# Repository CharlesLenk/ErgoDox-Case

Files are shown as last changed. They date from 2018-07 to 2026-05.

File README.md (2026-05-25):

# ErgoDox Case

ErgoDox keyboard case designed for FDM 3D printing

The original 3D print ErgoDox case had many overhangs that made it very difficult to print on a consumer grade printer.
It was also impossible to repair/replace any of the ports without fully desoldering the key switches.

This is a simplified case that’s possible to print at home. It’s in three parts, including a back cover that can be
removed to access the ports without desoldering the whole board.

The case is designed for m2 screws. Five 6mm screws and three 10mm screws are needed per hand.

## Printing

This model is designed to be printed on a standard consumer grade FDM printer. A a 0.4mm nozzle with a 0.2mm layer
height. Using PLA filament is recommended because it's low
cost and handles overhangs well. All parts can be printed without supports.

## Files in this repository

The stl directory contains the generated keyboard case files.

The source code for the design is in keyboard_case.scad. The distance numbers in the code may look awful, this is because the ErgoDox PCB used a mix of fractional inches, decimal inches, and millimeters, which were all normalized to millimeters in this design.

# Project Setup for Local Editing

Everything below this point is only relevant if you want to download this project and make edits.

## Cloning this Repository

This project uses a submodule for common SCAD code. If the submodule is not initialized, the `openscad-utilities`
directory will be empty, and the project won't render.

To get the submodule code when cloning, add the `--recurse-submodules` option to the clone command. For example:
> `git clone [Project URL] --recurse-submodules`

If you've already cloned the project, run this command in the project root to pull down the submodule:
> `git submodule update --init`

## Exporting Model Files

There are two options for exporting the models:

1. Manually through the [OpenSCAD](https://openscad.org/) UI.
2. Through the provided export script.

As of 2024, the OpenSCAD development preview uses a new rendering engine called Manifold. Using the development preview
with Manifold will render the models many times faster, regardless of how you export this project.

### 1. Exporting Manually

The `export map.scad` file contains an `if/else` condition where the call to generate each part can be seen. You can
either write OpenSCAD code using these calls to build up a print plate, or the part "name" can be manually edited to
select each part, which can then be rendered and exported through the OpenSCAD UI like any other project.

### 2. Exporting using the Script

The export script, `export.py`, depends on the [SCAD Export](https://github.com/CharlesLenk/scad_export) library. To use
this script follow the instructions in the SCAD Export documentation.

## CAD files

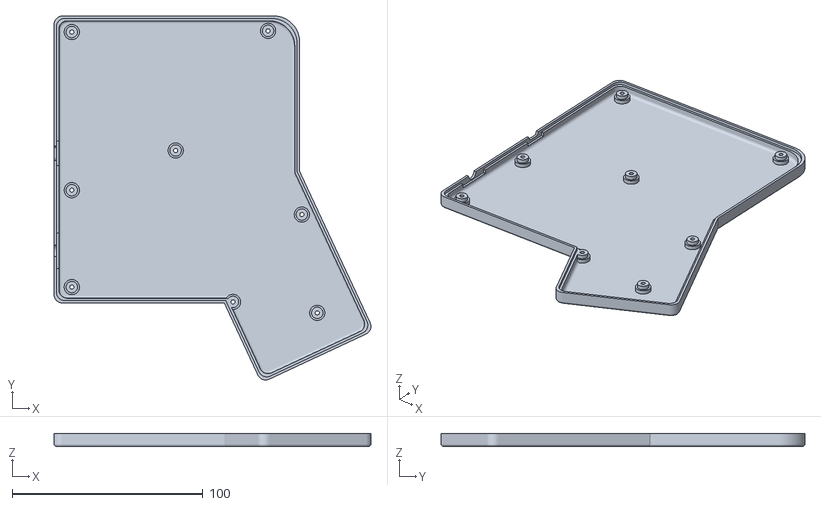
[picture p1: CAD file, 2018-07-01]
stl/bottom_right_case.stl
166.2 x 190.9 x 7.00

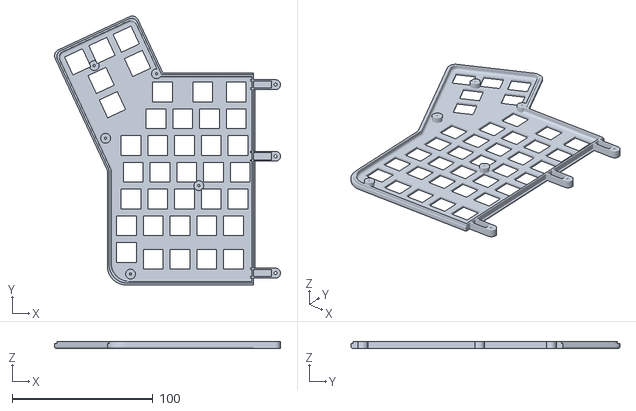
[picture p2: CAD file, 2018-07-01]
stl/top_left_case.stl
160.4 x 190.9 x 5.00

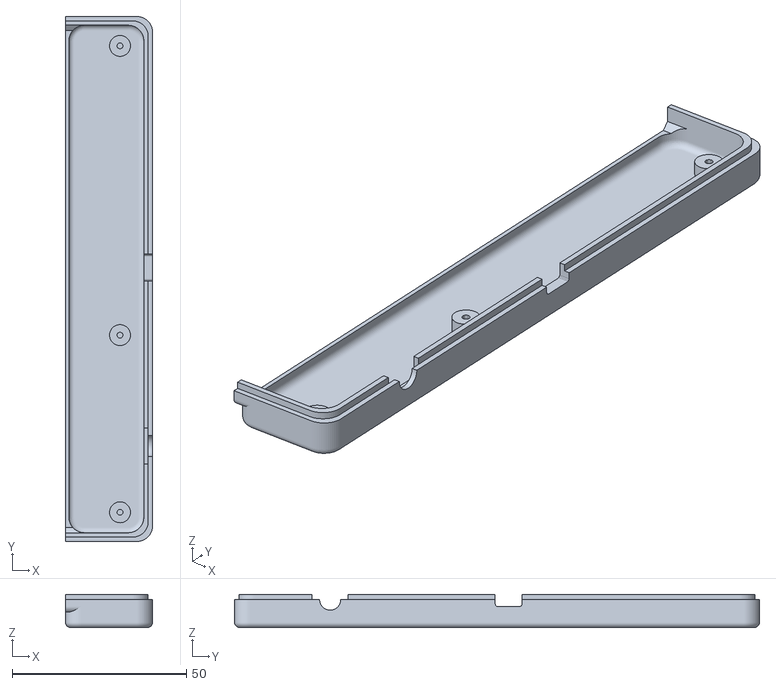
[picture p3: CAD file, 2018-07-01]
stl/cover_right_case.stl
25.0 x 150.5 x 9.50

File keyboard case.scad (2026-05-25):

include <openscad-utilities/common.scad>

switch_cut_size = 14;
switch_cut_margin = 5;
switch_spacing = switch_cut_size + switch_cut_margin;
wall_thickness = 2.5;
plate_thickness = 1.5;
pcb_wall_space = 1.5;

teensy_x_dimension = 25;
outer_row_y_offset = 4.7625;

outer_column_x_offset = 4.7752;
middle_column_x_offset = 1.5977;
inner_column_x_offset = 2.8702;

case_body_x = teensy_x_dimension + 5 * switch_spacing + outer_column_x_offset + pcb_wall_space + wall_thickness;
case_body_y = 7 * switch_spacing + 2 * outer_row_y_offset + 2 * wall_thickness + 2 * pcb_wall_space;
thumb_size = 3 * switch_spacing + 2 * wall_thickness + 2 * pcb_wall_space;

surface_d = 3;
corner_d = 9;

height = 7.5 + 2 * plate_thickness;
electronics_cover_height = 4.5;
port_height = 7;

center_x = teensy_x_dimension + 2 * switch_spacing + middle_column_x_offset/2;
center_y = 3 * switch_spacing + 2 * outer_row_y_offset + wall_thickness + pcb_wall_space;

thumb_offset_x = center_x + 60.714092;
thumb_offset_y = center_y + 78.638974;

front_coordinates = [[center_x, center_y], 
                   [center_x + 48.4631, center_y - 62.7380],
                   [center_x + 66.1671, center_y + 33.6050], 
                   [center_x + 74.2441, center_y + 85.1412], 
                   [center_x + 30.0736, center_y + 79.3754]];                    
back_coordinates = [[center_x - 54.4576, center_y + 20.828], 
                   [center_x - 54.4576, center_y + 71.6284], 
                   [center_x - 54.4576, center_y - 62.103]];
coordinates = concat(front_coordinates, back_coordinates);

screw_passthrough_rad = 1.1;
screw_head_d = 4.2;

bottom_screw_post_height = 4;
top_screw_post_height = 3.5;

trrs_offset = center_y + 52.5784;
usb_offset = center_y + 1.3975;

trrs_notch_width = 17.5514 + 1;
usb_notch_width = 11.887 + 1;

if($preview) {
    left_assembly(explode = true);
    translate([0, 400])
        right_assembly(explode = true);
}

module left_assembly(explode = false) {
    explode_dist = explode ? 20 : 0;

    bottom_left();
    translate([0, 0, explode_dist])
        top_left();
    translate([0, 0, 2 * explode_dist])
        electronics_cover_left();
}

module right_assembly(explode = false) {
    explode_dist = explode ? 20 : 0;

    bottom_right();
    translate([0, 0, explode_dist])
        top_right();
    translate([0, 0, 2 * explode_dist])
        electronics_cover_right();
}

module bottom_left() {
    difference() {
        union() {
            difference() {
                case_shell(15);
                translate([-1, -1, port_height]) {
                    cube([500, 500, 10]); 
                }
                translate([0, 0, bottom_screw_post_height + plate_thickness + 0.001]) {
                    case_skirt(wall_thickness/2, wall_thickness + 0.001, 10);
                }                         
            }
            bottom_screw_posts();
        }
        place_at_coordinates(coordinates) {
            rotate([180, 0, 0])
                countersink(shaft_diameter = 2 * screw_passthrough_rad, head_size = screw_head_d, 1.5);
        }
        translate([0, trrs_offset, port_height]) {
            rotate([0, 90, 0]){
                cylinder(r=3, h=10, center=true);
            }
        }
        translate([wall_thickness, trrs_offset, port_height]) {
            cube([wall_thickness, trrs_notch_width, port_height], center=true);
        }
        translate([wall_thickness, usb_offset, port_height]) {
            cube([wall_thickness, usb_notch_width, port_height], center=true);
        }
    }   
}

module bottom_right() {
    mirror([0, 1, 0]) {
        difference() {
            bottom_left();
            translate([0, usb_offset, 7]) {
                usb_cutout();
            }
        }
    }
}

module top_left() {
    union() {
        difference() {
            union() {
                case_shell(height);
                difference() {
                    top_screw_posts();
                    translate([0, 0, port_height - top_screw_post_height + wall_thickness/2]) {
                        case_skirt(-2 * wall_thickness, wall_thickness - 0.001, top_screw_post_height);
                    }
                }
                translate([teensy_x_dimension, wall_thickness, height - top_screw_post_height - plate_thickness]) {
                    cube([1, case_body_y - 2*wall_thickness, top_screw_post_height]);
                }
            }
            translate([-1, -1, height - top_screw_post_height - plate_thickness - 10 - 0.001]) {
                cube([500, 500, 10]); 
            }
            translate([0, 0, port_height - wall_thickness/2 - 1]) {
                case_skirt(- 0.001,  wall_thickness/2, wall_thickness/2 + 1);
            }
            translate([-1, -1]) {
                cube([teensy_x_dimension + 1.001, case_body_y + 2, 20]); 
            }  
            screw_holes(front_coordinates, height - 1);
            key_cutouts();    
        }                   
        translate([teensy_x_dimension - 1, surface_d/2 + 4, height - 1.001]) {
            cube([1, case_body_y - surface_d - 8, 1]);
        }
        top_back_screw_posts();      
    }
}

module top_right() {
    mirror([0, 1, 0]) {
        top_left();
    }
}

module electronics_cover_left() {
    difference() {
        union() {
            difference() {
                union() {
                    top_cover_rectangle(0, 0, 0);
                    case_rectangle(height, 0, 0);
                }
                top_cover_rectangle(plate_thickness, wall_thickness, 1);
                translate([-1, -1, height - top_screw_post_height - plate_thickness - 10 - 0.001]) {
                    cube([500, 500, 10]); 
                }
                translate([teensy_x_dimension, -1, height + 0.001 - 10]) {
                    cube([500, 500, 10]); 
                }
                hull() {
                    translate([teensy_x_dimension - 6, wall_thickness + 1.5, height - 10]) {
                        cube([10, case_body_y - 2 * wall_thickness - 3, 10]); 
                    }
                    translate([teensy_x_dimension - 6, wall_thickness, height - plate_thickness - top_screw_post_height]) {
                        cube([10, case_body_y - 2 * wall_thickness, top_screw_post_height]); 
                    }
                }
                translate([0, 0, port_height - wall_thickness/2 - 1.001]) {
                    case_skirt(-0.001,  wall_thickness/2, wall_thickness/2 + 1);
                }                                 
            }
            place_at_coordinates(back_coordinates) {
                translate([0, 0, height]) {
                    cylinder(r=3,h=electronics_cover_height - plate_thickness);
                }
            }
        }
        translate([0, trrs_offset, 7]) {
            rotate([0,90,0]){
                cylinder(r=3, h=10, center=true);
            }
        }
        screw_holes(back_coordinates, height + electronics_cover_height - 1);
        translate([wall_thickness - 0.001, trrs_offset, 7]) {
            cube([wall_thickness, 10.3, 7], center=true);
        }
    }
    
    module top_cover_rectangle(height_offset, edge_offset, xOffset) {
        translate([edge_offset, edge_offset, height_offset]) {
            roundedCube(teensy_x_dimension - edge_offset - xOffset, case_body_y - 2 * edge_offset, height + electronics_cover_height - 2 * height_offset, corner_d, surface_d);
        }
    }
}

module electronics_cover_right() {
    mirror([0, 1, 0]) {
        difference() {
            electronics_cover_left();
            translate([0, usb_offset, 7]) {
                hull() {
                    usb_cutout();
                    translate([0, 0, -5]) {
                        usb_cutout();
                    }
                }
            }
        }
    }
}
    
module case_shell(height) {
    difference() {
        case_base(height, 0, 0);
        case_base(height, plate_thickness, wall_thickness);
    }
}    
    
module case_base(height, height_offset, edge_offset) {
    union() {
        case_rectangle(height, height_offset, edge_offset);
        translate([thumb_offset_x, thumb_offset_y, height_offset]){
            rotate(-25) {
                translate([-thumb_size/2 + edge_offset, -1.5 * thumb_size + edge_offset, 0]){
                    roundedCube(thumb_size - 2 * edge_offset, 2*thumb_size - 2 * edge_offset, height - 2 * height_offset, corner_d, surface_d);
                }
            }
        }
    }
}

module case_rectangle(height, height_offset, edge_offset) {
     translate([edge_offset, edge_offset, height_offset]) {
        roundedCube(case_body_x - 2 * edge_offset, case_body_y - 2 * edge_offset, height - 2 * height_offset, corner_d, surface_d, true);
    }
}
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

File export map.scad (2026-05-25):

include <openscad-utilities/common.scad>
use <keyboard case.scad>

name = "";

if (name == "bottom_right")
    rotate(90)
        bottom_right();
else if (name == "bottom_left")
    rotate(90)
        bottom_left();
else if (name == "top_right")
    rotate([180, 0, 90])
        top_right();
else if (name == "top_left")
    rotate([180, 0, 90])
        top_left();
else if (name == "electronics_cover_right")
    rotate([180, 0, 90])
        electronics_cover_right();
else if (name == "electronics_cover_left")
    rotate([180, 0, 90])
        electronics_cover_left();

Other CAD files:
stl/bottom_left_case.stl
stl/cover_left_case.stl
stl/top_right_case.stl

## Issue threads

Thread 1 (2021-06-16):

Handwire

matt-vdv, 2021-06-16:
Hi, I saw this project and thought it was great! It greatly reduces the print time.

However, I have one question. I am intending to handwire my Ergodox, rather than use a PCB. I'm guessing that for this case the switches are normally supported by the PCB, but would it be possible to use the top of the case to support them (like a plate)? Or would they not snap in properly?

CharlesLenk, 2023-06-19:
Hey, so I missed this years ago, but in case it's still helpful to you (or anyone else who may see this) you probably don't want to hand wire in this case. The switches do click into the plastic fairly solidly and won't feel loose, but the plastic is not very strong on its own and may lead to a somewhat mushy feeling keyboard without the PCB to add extra rigidity.

Closed 2023-06-19.

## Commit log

2026-05-25 Improved export; Project refactoring
    [export map.scad, keyboard case.scad, keyboard_case.scad]
2026-05-25 Improve code; Use snake case (#3)
    * Improve code; Use snake case
    * Added right handle assembly
    ---------
    [keyboard case.scad]
